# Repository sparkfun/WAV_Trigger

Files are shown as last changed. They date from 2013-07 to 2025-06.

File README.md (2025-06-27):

WAV Trigger
===============

WAV Trigger (https://www.sparkfun.com/products/13660)

[*WAV Trigger (WIG-13660)*](https://www.sparkfun.com/products/13660)

The WAV Trigger is similar to its cousin, the MP3 Trigger, however it plays .WAV files and allows them to be mixed on the fly. 

This board was created in Eagle v6.0.5.

Repository Contents
-------------------

* **/Hardware** - Eagle PCB layout files (.brd, .sch)
* **/Production** - Test bed files and production panel files

Documentation
--------------
* **[Arduino Library](https://github.com/robertsonics/WAV-Trigger-Arduino-Serial-Library)** - Arduino library for the WAV Trigger.
* **[Hookup Guide](https://learn.sparkfun.com/tutorials/wav-trigger-hookup-guide-v11)** - Basic hookup guide for the WAV Trigger.

Product Versions
----------------
* [WIG-13660](https://www.sparkfun.com/products/13660) - vH1.1
* [WIG-12897](https://www.sparkfun.com/products/12897) - vH1.1
* [WIG-13660](https://www.sparkfun.com/products/12000) - vH1.0

Version History
---------------
* vH11
* vH10 - First production run.

License Information
-------------------
All contents of this repository are released under [Creative Commons Share-alike 3.0](http://creativecommons.org/licenses/by-sa/3.0/).

Authors
--------
Jamie Robertson @ robertsonics
Jordan McConnell @ SparkFun Electronics

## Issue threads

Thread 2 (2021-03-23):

WTrigAdvanced won't compile on teensy 3.5

jackjaquejack, 2021-03-23:
Hi there.

Im trying to control the wav trigger via serial communication on the teensy 3.5, but it won't compile. It will compile with the teensy 3.6, and other teensy boards.  does anyone know what I could do to fix this? The project is large and has various pin expansion chips, rgb screens already. The awesome wav trigger is the final piece in the project, so it would be nice to be able to get it to compile. I've checked that I have the correct libs installed, and as I say it compiles on other teensy boards. Any help would be appreciated. error messages to follow, thank you!

/Users/Home/Documents/Arduino/libraries/Metro/Metro.cpp:42:16: warning: extra tokens at end of #ifdef directive
  #ifdef NOCATCH-UP
                ^
In file included from /Users/Home/Documents/Arduino/libraries/AltSoftSerial/AltSoftSerial.cpp:32:0:
/Users/Home/Documents/Arduino/libraries/AltSoftSerial/config/AltSoftSerial_Boards.h:136:2: error: #error "Please define your board timer and pins"
 #error "Please define your board timer and pins"
  ^
/Users/Home/Documents/Arduino/libraries/AltSoftSerial/AltSoftSerial.cpp: In static member function 'static void AltSoftSerial::init(uint32_t)':
/Users/Home/Documents/Arduino/libraries/AltSoftSerial/AltSoftSerial.cpp:68:27: error: 'CONFIG_TIMER_NOPRESCALE' was not declared in this scope
   CONFIG_TIMER_NOPRESCALE();
                           ^
/Users/Home/Documents/Arduino/libraries/AltSoftSerial/AltSoftSerial.cpp:72:28: error: 'CONFIG_TIMER_PRESCALE_8' was not declared in this scope
    CONFIG_TIMER_PRESCALE_8();
                            ^
/Users/Home/Documents/Arduino/libraries/AltSoftSerial/AltSoftSerial.cpp:79:10: error: 'INPUT_CAPTURE_PIN' was not declared in this scope
  pinMode(INPUT_CAPTURE_PIN, INPUT_PULLUP);
          ^
/Users/Home/Documents/Arduino/libraries/AltSoftSerial/AltSoftSerial.cpp:80:15: error: 'OUTPUT_COMPARE_A_PIN' was not declared in this scope
  digitalWrite(OUTPUT_COMPARE_A_PIN, HIGH);
               ^
/Users/Home/Documents/Arduino/libraries/AltSoftSerial/AltSoftSerial.cpp:88:27: error: 'ENABLE_INT_INPUT_CAPTURE' was not declared in this scope
  ENABLE_INT_INPUT_CAPTURE();
                           ^
/Users/Home/Documents/Arduino/libraries/AltSoftSerial/AltSoftSerial.cpp: In static member function 'static void AltSoftSerial::end()':
/Users/Home/Documents/Arduino/libraries/AltSoftSerial/AltSoftSerial.cpp:93:24: error: 'DISABLE_INT_COMPARE_B' was not declared in this scope
  DISABLE_INT_COMPARE_B();
                        ^
/Users/Home/Documents/Arduino/libraries/AltSoftSerial/AltSoftSerial.cpp:94:28: error: 'DISABLE_INT_INPUT_CAPTURE' was not declared in this scope
  DISABLE_INT_INPUT_CAPTURE();
                            ^
/Users/Home/Documents/Arduino/libraries/AltSoftSerial/AltSoftSerial.cpp:97:24: error: 'DISABLE_INT_COMPARE_A' was not declared in this scope
  DISABLE_INT_COMPARE_A();
                        ^
/Users/Home/Documents/Arduino/libraries/AltSoftSerial/AltSoftSerial.cpp: In static member function 'static void AltSoftSerial::writeByte(uint8_t)':
/Users/Home/Documents/Arduino/libraries/AltSoftSerial/AltSoftSerial.cpp:122:24: error: 'ENABLE_INT_COMPARE_A' was not declared in this scope
   ENABLE_INT_COMPARE_A();
                        ^
/Users/Home/Documents/Arduino/libraries/AltSoftSerial/AltSoftSerial.cpp:123:22: error: 'CONFIG_MATCH_CLEAR' was not declared in this scope
   CONFIG_MATCH_CLEAR();
                      ^
/Users/Home/Documents/Arduino/libraries/AltSoftSerial/AltSoftSerial.cpp:124:33: error: 'GET_TIMER_COUNT' was not declared in this scope
   SET_COMPARE_A(GET_TIMER_COUNT() + 16);
                                 ^
/Users/Home/Documents/Arduino/libraries/AltSoftSerial/AltSoftSerial.cpp:124:39: error: 'SET_COMPARE_A' was not declared in this scope
   SET_COMPARE_A(GET_TIMER_COUNT() + 16);
                                       ^
/Users/Home/Documents/Arduino/libraries/AltSoftSerial/AltSoftSerial.cpp: At global scope:
/Users/Home/Documents/Arduino/libraries/AltSoftSerial/AltSoftSerial.cpp:130:4: error: expected constructor, destructor, or type conversion before '(' token
 ISR(COMPARE_A_INTERRUPT)
    ^
/Users/Home/Documents/Arduino/libraries/AltSoftSerial/AltSoftSerial.cpp:43:16: warning: 'rx_byte' defined but not used [-Wunused-variable]
 static uint8_t rx_byte;
                ^
/Users/Home/Documents/Arduino/libraries/AltSoftSerial/AltSoftSerial.cpp:44:16: warning: 'rx_bit' defined but not used [-Wunused-variable]
 static uint8_t rx_bit = 0;
                ^
/Users/Home/Documents/Arduino/libraries/AltSoftSerial/AltSoftSerial.cpp:45:17: warning: 'rx_target' defined but not used [-Wunused-variable]
 static uint16_t rx_target;
                 ^
Multiple libraries were found for "Metro.h"
 Used: /Users/Home/Documents/Arduino/libraries/Metro
 Not used: /private/var/folders/lc/3yqb2gz925d1czhsmn2cnz4r0000gn/T/AppTranslocation/9FE4EA52-FF66-48F3-A1C6-21D8DF2A8493/d/Teensyduino.app/Contents/Java/hardware/teensy/avr/libraries/Metro
Multiple libraries were found for "AltSoftSerial.h"
 Used: /Users/Home/Documents/Arduino/libraries/AltSoftSerial
 Not used: /Users/Home/Documents/Arduino/libraries/AltSoftSerial-master
 Not used: /private/var/folders/lc/3yqb2gz925d1czhsmn2cnz4r0000gn/T/AppTranslocation/9FE4EA52-FF66-48F3-A1C6-21D8DF2A8493/d/Teensyduino.app/Contents/Java/hardware/teensy/avr/libraries/AltSoftSerial
Error compiling for board Teensy 3.5.

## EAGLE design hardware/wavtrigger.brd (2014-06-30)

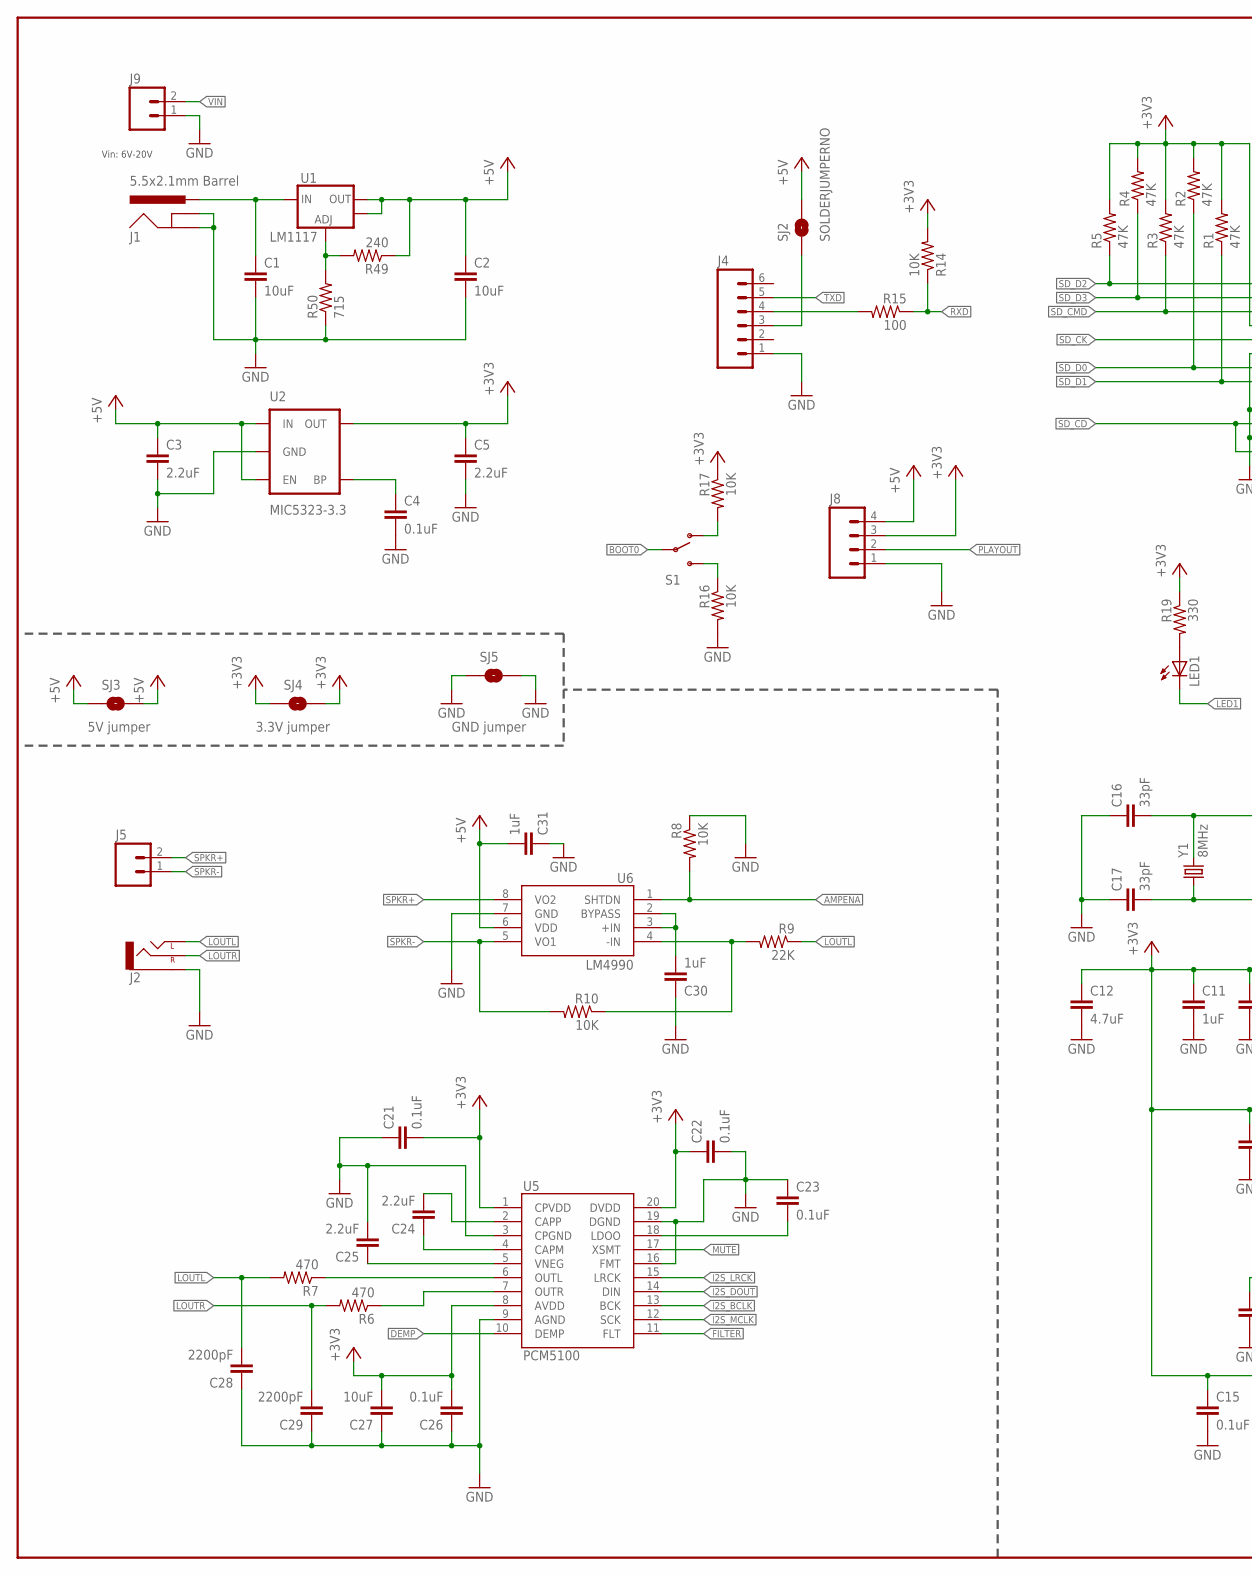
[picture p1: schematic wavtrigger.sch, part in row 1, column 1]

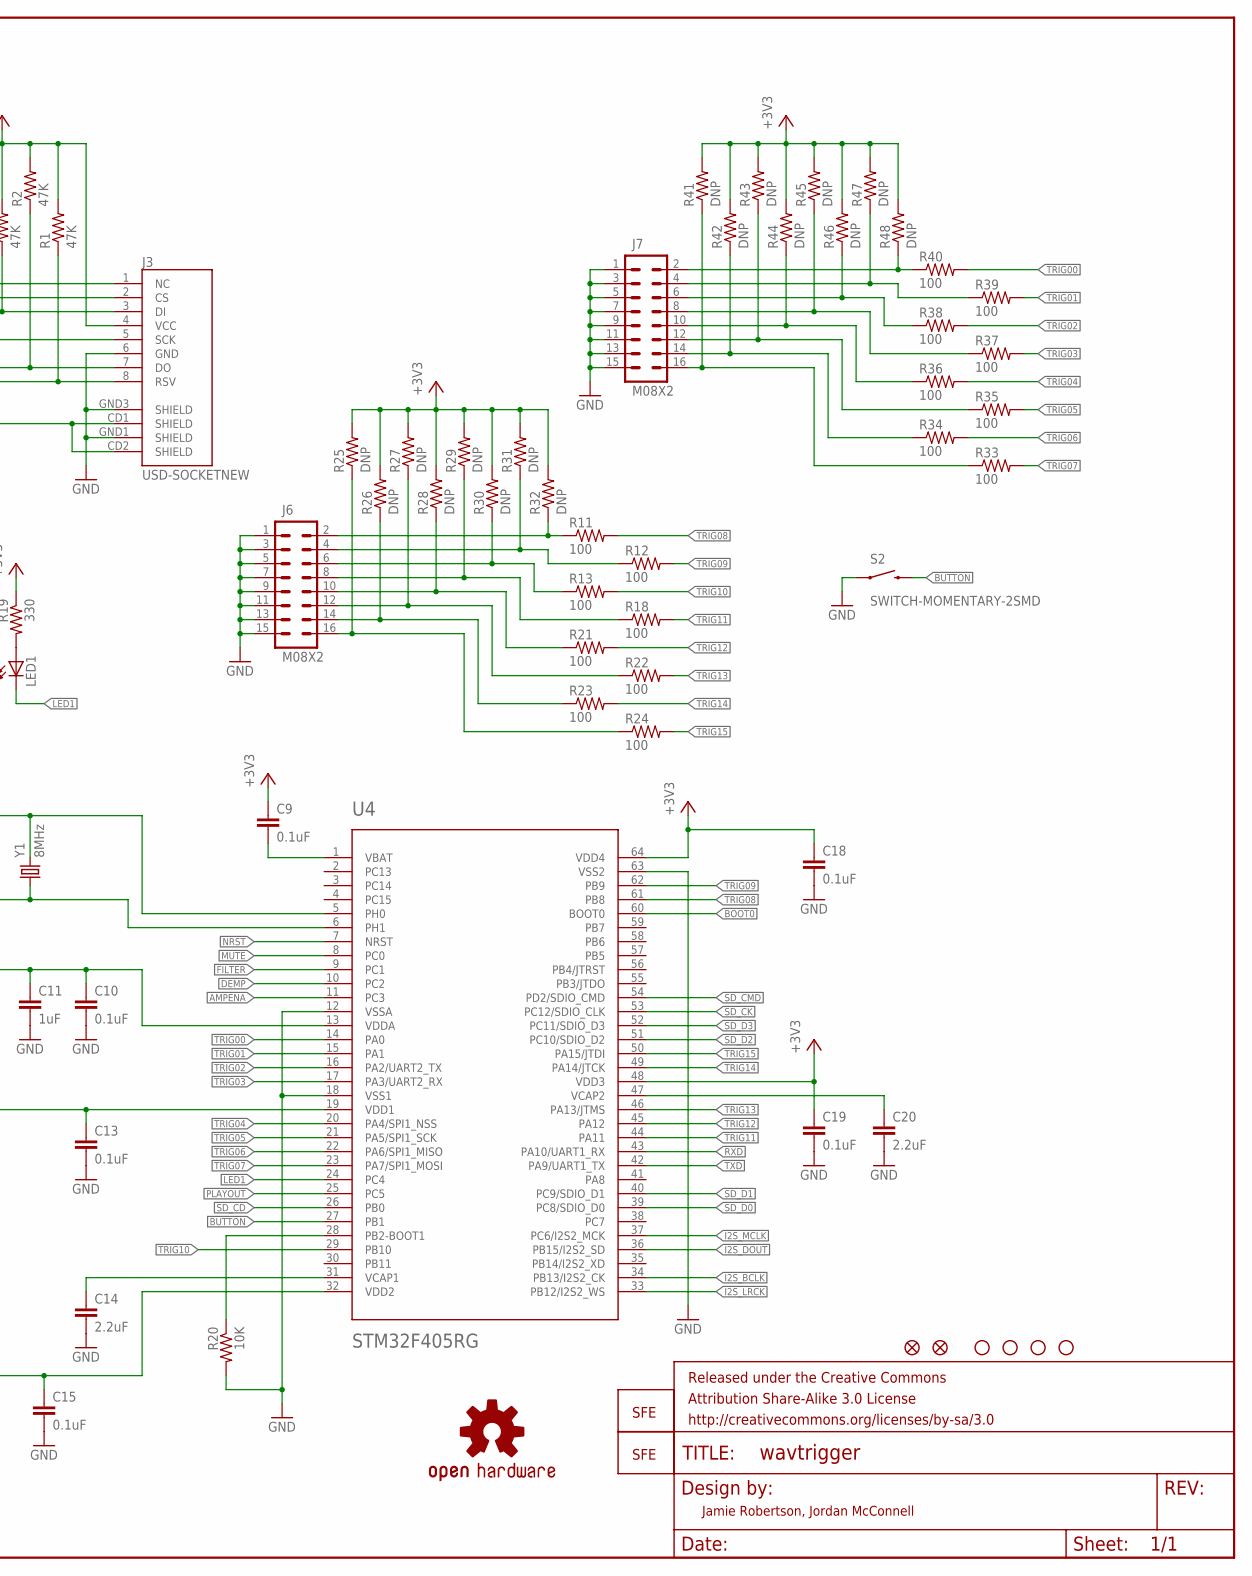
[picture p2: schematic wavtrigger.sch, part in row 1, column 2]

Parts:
C1: 10uF; 1210
C2: 10uF; 0805
C3, C5: 2.2uF; 0805
C4, C9, C10, C13, C15, C18, C19, C21, C22, C23, C26: 0.1uF; 0603-CAP
C11, C30, C31: 1uF; 0603-CAP
C12: 4.7uF; 0603-CAP
C14, C20, C24, C25: 2.2uF; 0603-CAP
C16, C17: 33pF; 0603-CAP
C27: 10uF; 0603-CAP
C28, C29: 2200pF; 0603-CAP
FID1, FID2: FIDUCIAL1X2; FIDUCIAL-1X2
FRAME2: FRAME-LEDGER; CREATIVE_COMMONS
J1: 5.5x2.1mm Barrel; POWER_JACK_SMD
J2: AUDIO-JACKSMD2; AUDIO-JACK-3.5MM-SMD
J3: USD-SOCKETNEW; MICRO-SD-SOCKET-PP
J4: M06SIP; 1X06
J5, J9: M02PTH; 1X02
J6, J7: M08X2; 2X8
J8: M04PTH; 1X04
LED1: LED0603; LED-0603
LOGO1: OSHW-LOGOL; OSHW-LOGO-L
LOGO2: LOGO-SFENEW; SFE-NEW-WEBLOGO
LOGO3: LOGO-SFESK; SFE-LOGO-FLAME
R1, R2, R3, R4, R5: 47K; 0603-RES
R6, R7: 470; 0603-RES
R8, R10, R14, R16, R17, R20: 10K; 0603-RES
R9: 22K; 0603-RES
R11, R12, R13, R15, R18, R21, R22, R23, R24, R33, R34, R35, R36, R37, R38, R39, R40: 100; 0603-RES
R19: 330; 0603-RES
R25, R26, R27, R28, R29, R30, R31, R32, R41, R42, R43, R44, R45, R46, R47, R48: DNP; 0603-RES
R49: 240; 0603-RES
R50: 715; 0603-RES
S1: SWITCH-SPDT-SMD-A; SWITCH-SPST-SMD-A
S2: SWITCH-MOMENTARY-2SMD; TACTILE_SWITCH_SMD
SJ2: SOLDERJUMPERNO; SJ_2S-NO
SJ3, SJ4, SJ5: SOLDERJUMPERTRACE; SJ_2S-TRACE
STANDOFF1, STANDOFF2, STANDOFF3, STANDOFF4: STAND-OFF
U1: V_REG_LM1117SOT223; SOT223
U2: MIC5323-3.3; SOT23-5
U4: STM32F405RG; TQFP64
U5: PCM5100; PW_R-PDSO-G20
U6: LM4990; S-PDSO-G08
Y1: 8MHz; HC49UP

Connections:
+5V: C2.1, C3.1, C31.2, J8.4, R49.1, SJ2.2, SJ3.1, SJ3.2, U1.2 (OUT), U1.4 (OUT), U2.1 (IN), U2.3 (EN), U6.6 (VDD)
AMPENA: R8.2, U4.11 (PC3), U6.1 (SHTDN)
BOOT0: S1.2, U4.60 (BOOT0)
BUTTON: S2.3 (2), U4.27 (PB1)
DEMP: U4.10 (PC2), U5.10 (DEMP)
FILTER: U4.9 (PC1), U5.11 (FLT)
GND: C1.2, C2.2, C3.2, C4.2, C5.2, C10.2, C11.2, C12.2, C13.2, C14.2, C15.2, C16.1, C17.1, C18.2, C19.2, C20.2, C21.1, C22.2, C23.1, C25.2, C26.1, C27.1, C28.1, C29.1, C30.1, C31.1, J1.GND (GNDBREAK), J1.P$4 (GND), J2.SLEEVE, J3.6 (GND), J3.GND1 (SHIELD), J3.GND3 (SHIELD), J4.1, J6.1, J6.3, J6.5, J6.7, J6.9, J6.11, J6.13, J6.15, J7.1, J7.3, J7.5, J7.7, J7.9, J7.11, J7.13, J7.15, J8.1, J9.1, R8.1, R16.2, R20.2, R50.1, S2.1, SJ5.1, SJ5.2, U2.2 (GND), U4.12 (VSSA), U4.18 (VSS1), U4.63 (VSS2), U5.3 (CPGND), U5.9 (AGND), U5.16 (FMT), U5.19 (DGND), U6.7 (GND)
I2S_BCLK: U4.34 (PB13/I2S2_CK), U5.13 (BCK)
I2S_DOUT: U4.36 (PB15/I2S2_SD), U5.14 (DIN)
I2S_LRCK: U4.33 (PB12/I2S2_WS), U5.15 (LRCK)
I2S_MCLK: U4.37 (PC6/I2S2_MCK), U5.12 (SCK)
LED1: LED1.C, U4.24 (PC4)
LOUTL: C28.2, J2.TIP (LEFT), R7.2, R9.1
LOUTR: C29.2, J2.RING (RIGHT), R6.2
MUTE: U4.8 (PC0), U5.17 (XSMT)
unnamed: J6.2, R11.1, R32.1
unnamed: C4.1, U2.4 (BP)
unnamed: C9.2, U4.1 (VBAT)
unnamed: C14.1, U4.31 (VCAP1)
unnamed: C16.2, U4.5 (PH0), Y1.2
unnamed: C17.2, U4.6 (PH1), Y1.1
unnamed: R16.1, S1.3 (S)
unnamed: C20.1, U4.47 (VCAP2)
unnamed: J4.4, R15.2
unnamed: R17.2, S1.1 (O)
unnamed: LED1.A, R19.2
unnamed: R20.1, U4.28 (PB2-BOOT1)
unnamed: R49.2, R50.2, U1.1 (ADJ)
unnamed: C23.2, U5.18 (LDOO)
unnamed: R6.1, U5.7 (OUTR)
unnamed: C24.2, U5.2 (CAPP)
unnamed: C24.1, U5.4 (CAPM)
unnamed: C25.1, U5.5 (VNEG)
unnamed: R7.1, U5.6 (OUTL)
unnamed: C30.2, U6.2 (BYPASS), U6.3 (+IN)
unnamed: J6.4, R12.1, R31.1
unnamed: J6.6, R13.1, R30.1
unnamed: J6.8, R18.1, R29.1
unnamed: J6.10, R21.1, R28.1
unnamed: J6.12, R22.1, R27.1
unnamed: J6.14, R23.1, R26.1
unnamed: R9.2, R10.1, U6.4 (-IN)
unnamed: J6.16, R24.1, R25.1
unnamed: J4.3, SJ2.1
unnamed: J7.2, R40.1, R48.1
unnamed: J7.4, R39.1, R47.1
unnamed: J7.6, R38.1, R46.1
unnamed: J7.8, R37.1, R45.1
unnamed: J7.10, R36.1, R44.1
unnamed: J7.12, R35.1, R43.1
unnamed: J7.14, R34.1, R42.1
unnamed: J7.16, R33.1, R41.1
NRST: U4.7 (NRST)
PLAYOUT: J8.2, U4.25 (PC5)
RXD: R14.1, R15.1, U4.43 (PA10/UART1_RX)
SD_CD: J3.CD1 (SHIELD), J3.CD2 (SHIELD), U4.26 (PB0)
SD_CK: J3.5 (SCK), U4.53 (PC12/SDIO_CLK)
SD_CMD: J3.3 (DI), R3.1, U4.54 (PD2/SDIO_CMD)
SD_D0: J3.7 (DO), R2.1, U4.39 (PC8/SDIO_D0)
SD_D1: J3.8 (RSV), R1.1, U4.40 (PC9/SDIO_D1)
SD_D2: J3.1 (NC), R5.1, U4.51 (PC10/SDIO_D2)
SD_D3: J3.2 (CS), R4.1, U4.52 (PC11/SDIO_D3)
SPKR+: J5.2, U6.8 (VO2)
SPKR-: J5.1, R10.2, U6.5 (VO1)
TRIG00: R40.2, U4.14 (PA0)
TRIG01: R39.2, U4.15 (PA1)
TRIG02: R38.2, U4.16 (PA2/UART2_TX)
TRIG03: R37.2, U4.17 (PA3/UART2_RX)
TRIG04: R36.2, U4.20 (PA4/SPI1_NSS)
TRIG05: R35.2, U4.21 (PA5/SPI1_SCK)
TRIG06: R34.2, U4.22 (PA6/SPI1_MISO)
TRIG07: R33.2, U4.23 (PA7/SPI1_MOSI)
TRIG08: R11.2, U4.61 (PB8)
TRIG09: R12.2, U4.62 (PB9)
TRIG10: R13.2, U4.29 (PB10)
TRIG11: R18.2, U4.44 (PA11)
TRIG12: R21.2, U4.45 (PA12)
TRIG13: R22.2, U4.46 (PA13/JTMS)
TRIG14: R23.2, U4.49 (PA14/JTCK)
TRIG15: R24.2, U4.50 (PA15/JTDI)
TXD: J4.5, U4.42 (PA9/UART1_TX)
VCC: C5.1, C9.1, C10.1, C11.1, C12.1, C13.1, C15.1, C18.1, C19.1, C21.2, C22.1, C26.2, C27.2, J3.4 (VCC), J8.3, R1.2, R2.2, R3.2, R4.2, R5.2, R14.2, R17.1, R19.1, R25.2, R26.2, R27.2, R28.2, R29.2, R30.2, R31.2, R32.2, R41.2, R42.2, R43.2, R44.2, R45.2, R46.2, R47.2, R48.2, SJ4.1, SJ4.2, U2.5 (OUT), U4.13 (VDDA), U4.19 (VDD1), U4.32 (VDD2), U4.48 (VDD3), U4.64 (VDD4), U5.1 (CPVDD), U5.8 (AVDD), U5.20 (DVDD)
VIN: C1.1, J1.VIN0 (PWR), J9.2, U1.3 (IN)

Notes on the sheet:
Jamie Robertson, Jordan McConnell
5V jumper
3.3V jumper
GND jumper
LM1117
Vin: 6V-20V

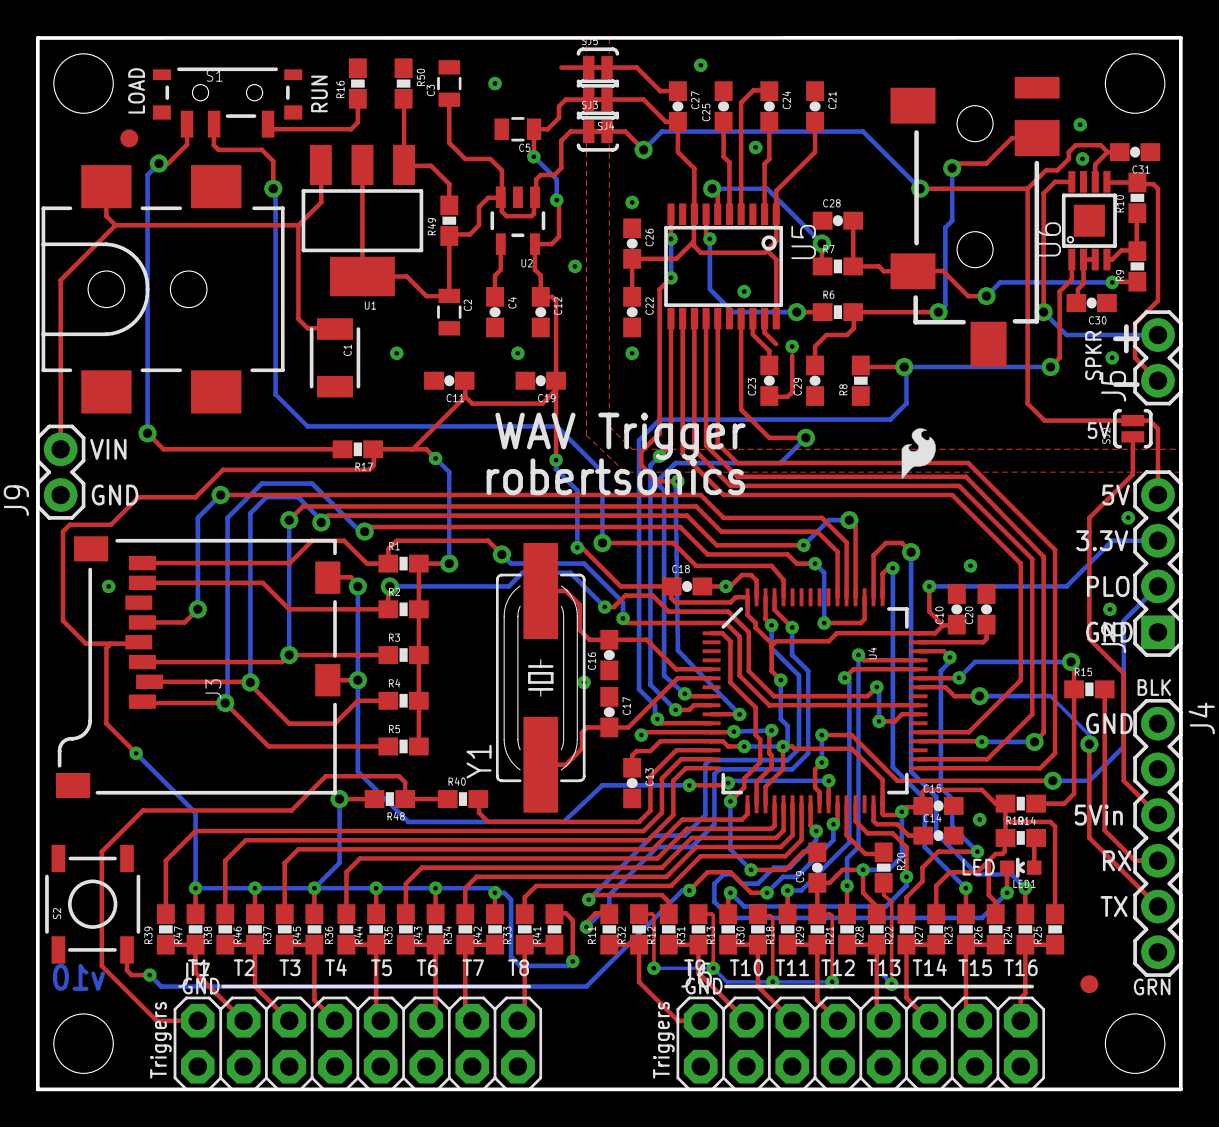
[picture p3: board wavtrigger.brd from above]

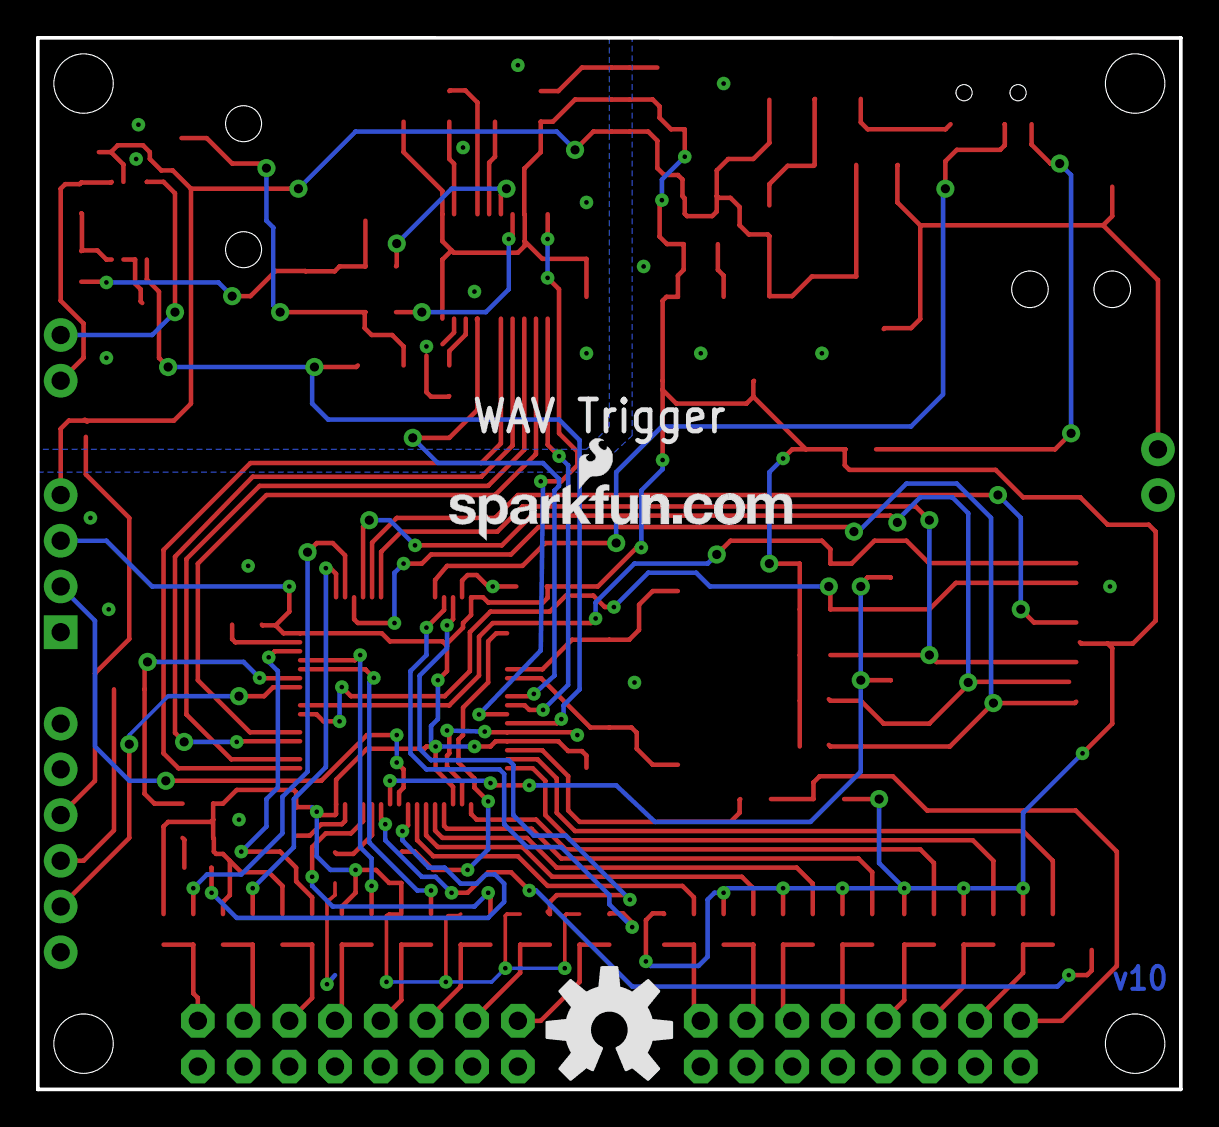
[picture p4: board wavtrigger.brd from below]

Board: 2 copper layers, 63.5 x 58.4 mm, 110 parts (2 on the bottom side), 82 nets.

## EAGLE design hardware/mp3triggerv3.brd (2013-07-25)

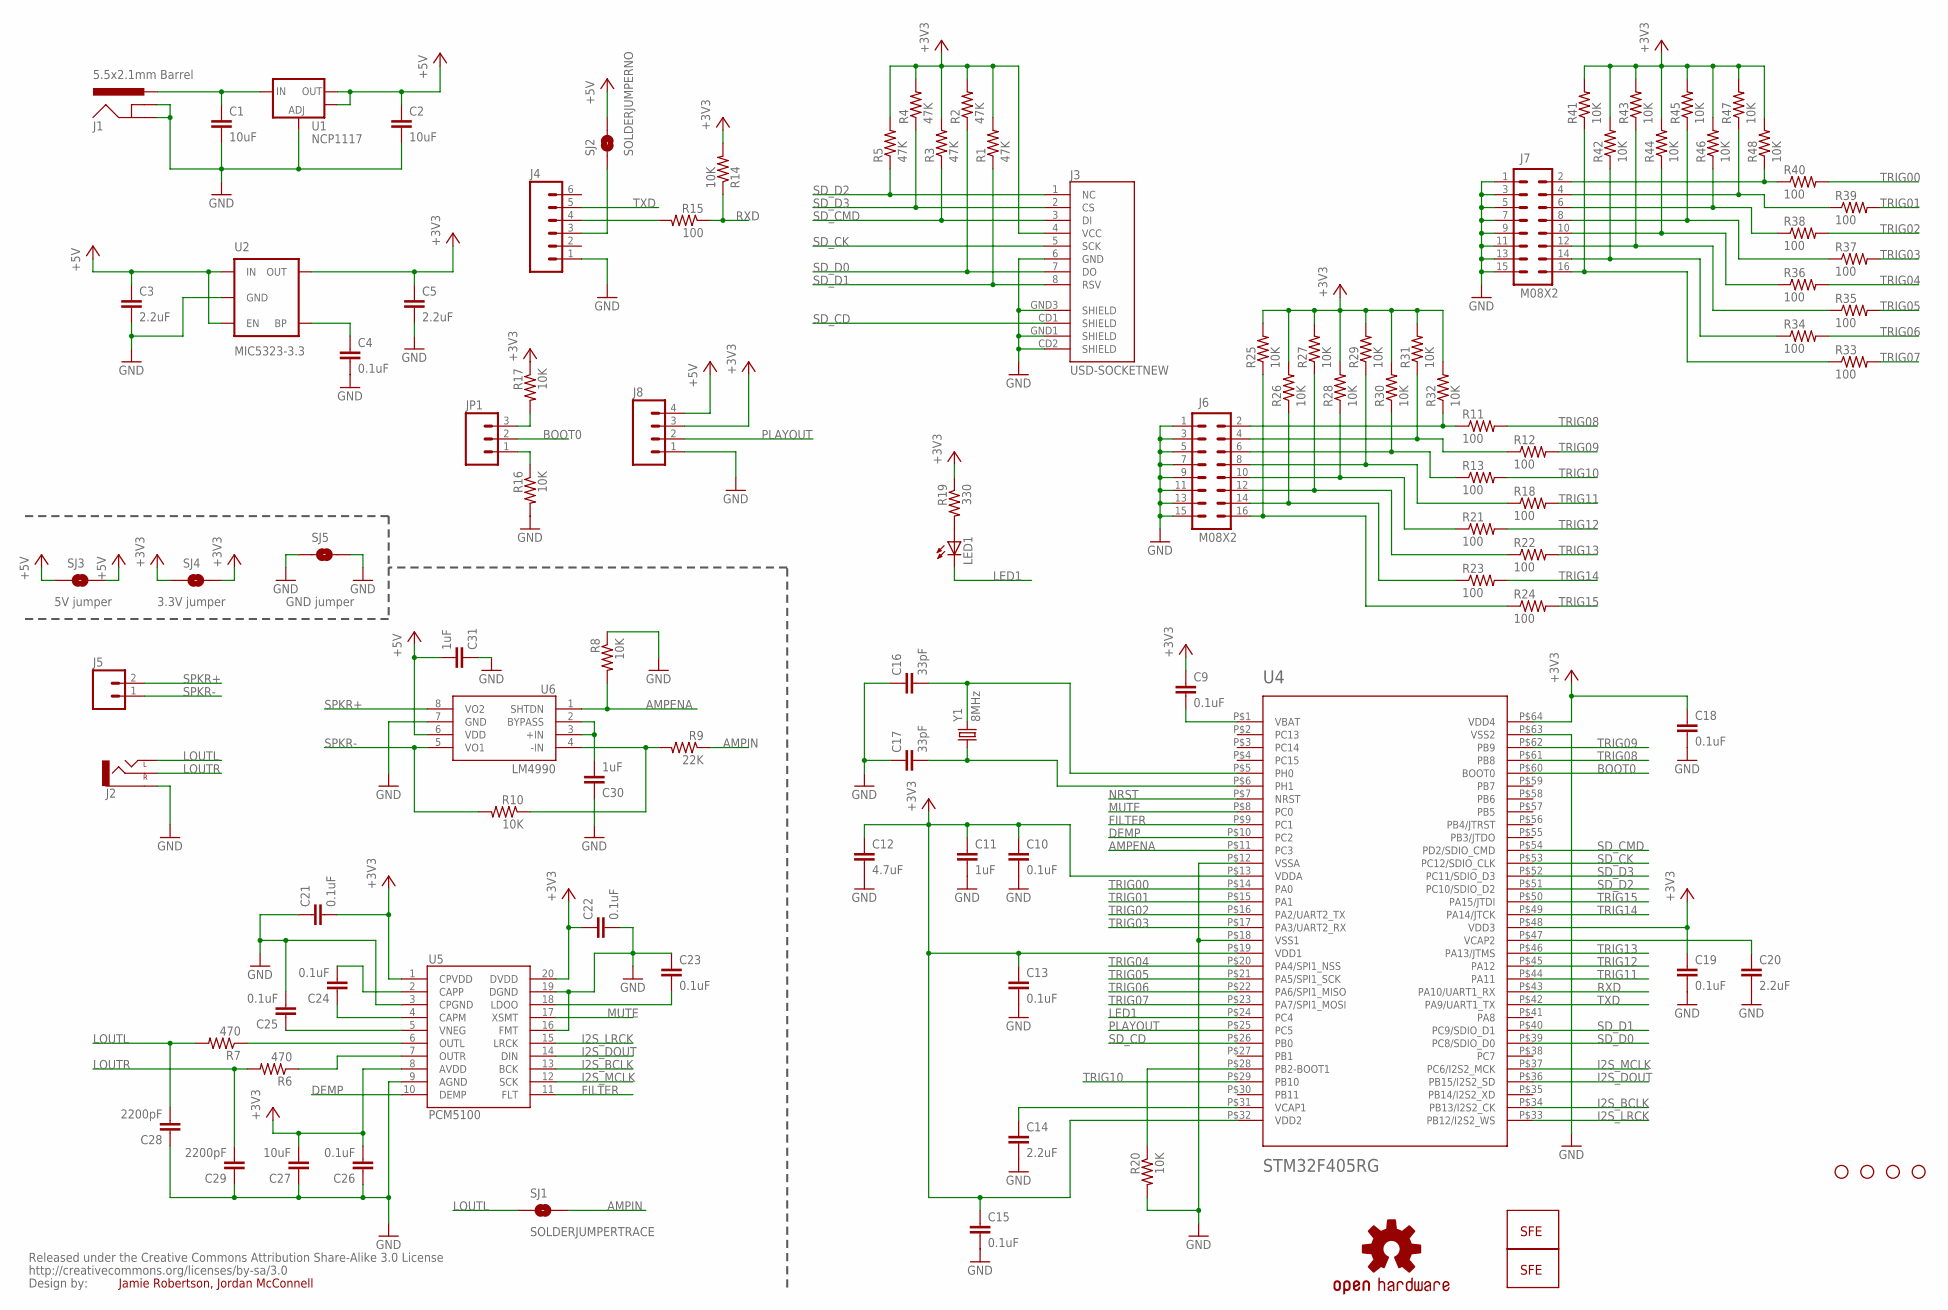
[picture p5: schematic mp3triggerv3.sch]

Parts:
C1: 10uF; 1210
C2: 10uF; 0805
C3, C5: 2.2uF; 0805
C4, C9, C10, C13, C15, C18, C19, C21, C22, C23, C24, C25, C26: 0.1uF; 0603-CAP
C11, C30, C31: 1uF; 0603-CAP
C12: 4.7uF; 0603-CAP
C14, C20: 2.2uF; 0603-CAP
C16, C17: 33pF; 0603-CAP
C27: 10uF; 0603-CAP
C28, C29: 2200pF; 0603-CAP
CC_TEXT1: CREATIVE_COMMONS
J1: 5.5x2.1mm Barrel; POWER_JACK_SMD
J2: AUDIO-JACKSMD2; AUDIO-JACK-3.5MM-SMD
J3: USD-SOCKETNEW; MICRO-SD-SOCKET-PP
J4: M06SIP; 1X06
J5: M02PTH; 1X02
J6, J7: M08X2; 2X8
J8: M04PTH; 1X04
JP1: M03PTH; 1X03
LED1: LED0603; LED-0603
LOGO1: OSHW-LOGOL; OSHW-LOGO-L
LOGO2: LOGO-SFENEW; SFE-NEW-WEBLOGO
LOGO3: LOGO-SFESK; SFE-LOGO-FLAME
R1, R2, R3, R4, R5: 47K; 0603-RES
R6, R7: 470; 0603-RES
R8, R10, R14, R16, R17, R20, R25, R26, R27, R28, R29, R30, R31, R32, R41, R42, R43, R44, R45, R46, R47, R48: 10K; 0603-RES
R9: 22K; 0603-RES
R11, R12, R13, R15, R18, R21, R22, R23, R24, R33, R34, R35, R36, R37, R38, R39, R40: 100; 0603-RES
R19: 330; 0603-RES
SJ1, SJ3, SJ4, SJ5: SOLDERJUMPERTRACE; SJ_2S-TRACE
SJ2: SOLDERJUMPERNO; SJ_2S-NO
STANDOFF1, STANDOFF2, STANDOFF3, STANDOFF4: STAND-OFF
U1: NCP1117; SOT223
U2: MIC5323-3.3; SOT23-5
U4: STM32F405RG; TQFP-10X10-64
U5: PCM5100; PW_R-PDSO-G20
U6: LM4990; S-PDSO-G08
Y1: 8MHz; HC49UP

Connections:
+5V: C2.1, C3.1, C31.2, J8.4, SJ2.2, SJ3.1, SJ3.2, U1.2 (OUT), U1.4 (OUT), U2.1 (IN), U2.3 (EN), U6.6 (VDD)
AMPENA: R8.2, U4.P$11 (PC3), U6.1 (SHTDN)
AMPIN: R9.1, SJ1.2
BOOT0: JP1.2, U4.P$60 (BOOT0)
DEMP: U4.P$10 (PC2), U5.10 (DEMP)
FILTER: U4.P$9 (PC1), U5.11 (FLT)
GND: C1.2, C2.2, C3.2, C4.2, C5.2, C10.2, C11.2, C12.2, C13.2, C14.2, C15.2, C16.1, C17.1, C18.2, C19.2, C20.2, C21.1, C22.2, C23.1, C25.2, C26.1, C27.1, C28.1, C29.1, C30.1, C31.1, J1.GND (GNDBREAK), J1.P$4 (GND), J2.SLEEVE, J3.6 (GND), J3.CD2 (SHIELD), J3.GND1 (SHIELD), J3.GND3 (SHIELD), J4.1, J6.1, J6.3, J6.5, J6.7, J6.9, J6.11, J6.13, J6.15, J7.1, J7.3, J7.5, J7.7, J7.9, J7.11, J7.13, J7.15, J8.1, R8.1, R16.2, R20.2, SJ5.1, SJ5.2, U1.1 (ADJ), U2.2 (GND), U4.P$12 (VSSA), U4.P$18 (VSS1), U4.P$63 (VSS2), U5.3 (CPGND), U5.9 (AGND), U5.16 (FMT), U5.19 (DGND), U6.7 (GND)
I2S_BCLK: U4.P$34 (PB13/I2S2_CK), U5.13 (BCK)
I2S_DOUT: U4.P$36 (PB15/I2S2_SD), U5.14 (DIN)
I2S_LRCK: U4.P$33 (PB12/I2S2_WS), U5.15 (LRCK)
I2S_MCLK: U4.P$37 (PC6/I2S2_MCK), U5.12 (SCK)
LED1: LED1.C, U4.P$24 (PC4)
LOUTL: C28.2, J2.TIP (LEFT), R7.2, SJ1.1
LOUTR: C29.2, J2.RING (RIGHT), R6.2
MUTE: U4.P$8 (PC0), U5.17 (XSMT)
unnamed: J6.2, R11.1, R32.1
unnamed: C4.1, U2.4 (BP)
unnamed: C9.2, U4.P$1 (VBAT)
unnamed: C14.1, U4.P$31 (VCAP1)
unnamed: C16.2, U4.P$5 (PH0), Y1.2
unnamed: C17.2, U4.P$6 (PH1), Y1.1
unnamed: JP1.1, R16.1
unnamed: C20.1, U4.P$47 (VCAP2)
unnamed: J4.4, R15.2
unnamed: JP1.3, R17.2
unnamed: LED1.A, R19.2
unnamed: R20.1, U4.P$28 (PB2-BOOT1)
unnamed: C23.2, U5.18 (LDOO)
unnamed: R6.1, U5.7 (OUTR)
unnamed: C24.2, U5.2 (CAPP)
unnamed: C24.1, U5.4 (CAPM)
unnamed: C25.1, U5.5 (VNEG)
unnamed: R7.1, U5.6 (OUTL)
unnamed: C30.2, U6.2 (BYPASS), U6.3 (+IN)
unnamed: J6.4, R12.1, R31.1
unnamed: J6.6, R13.1, R30.1
unnamed: J6.8, R18.1, R29.1
unnamed: J6.10, R21.1, R28.1
unnamed: J6.12, R22.1, R27.1
unnamed: J6.14, R23.1, R26.1
unnamed: R9.2, R10.1, U6.4 (-IN)
unnamed: J6.16, R24.1, R25.1
unnamed: J4.3, SJ2.1
unnamed: J7.2, R40.1, R48.1
unnamed: J7.4, R39.1, R47.1
unnamed: J7.6, R38.1, R46.1
unnamed: J7.8, R37.1, R45.1
unnamed: J7.10, R36.1, R44.1
unnamed: J7.12, R35.1, R43.1
unnamed: J7.14, R34.1, R42.1
unnamed: J7.16, R33.1, R41.1
NRST: U4.P$7 (NRST)
PLAYOUT: J8.2, U4.P$25 (PC5)
RXD: R14.1, R15.1, U4.P$43 (PA10/UART1_RX)
SD_CD: J3.CD1 (SHIELD), U4.P$26 (PB0)
SD_CK: J3.5 (SCK), U4.P$53 (PC12/SDIO_CLK)
SD_CMD: J3.3 (DI), R3.1, U4.P$54 (PD2/SDIO_CMD)
SD_D0: J3.7 (DO), R2.1, U4.P$39 (PC8/SDIO_D0)
SD_D1: J3.8 (RSV), R1.1, U4.P$40 (PC9/SDIO_D1)
SD_D2: J3.1 (NC), R5.1, U4.P$51 (PC10/SDIO_D2)
SD_D3: J3.2 (CS), R4.1, U4.P$52 (PC11/SDIO_D3)
SPKR+: J5.2, U6.8 (VO2)
SPKR-: J5.1, R10.2, U6.5 (VO1)
TRIG00: R40.2, U4.P$14 (PA0)
TRIG01: R39.2, U4.P$15 (PA1)
TRIG02: R38.2, U4.P$16 (PA2/UART2_TX)
TRIG03: R37.2, U4.P$17 (PA3/UART2_RX)
TRIG04: R36.2, U4.P$20 (PA4/SPI1_NSS)
TRIG05: R35.2, U4.P$21 (PA5/SPI1_SCK)
TRIG06: R34.2, U4.P$22 (PA6/SPI1_MISO)
TRIG07: R33.2, U4.P$23 (PA7/SPI1_MOSI)
TRIG08: R11.2, U4.P$61 (PB8)
TRIG09: R12.2, U4.P$62 (PB9)
TRIG10: R13.2, U4.P$29 (PB10)
TRIG11: R18.2, U4.P$44 (PA11)
TRIG12: R21.2, U4.P$45 (PA12)
TRIG13: R22.2, U4.P$46 (PA13/JTMS)
TRIG14: R23.2, U4.P$49 (PA14/JTCK)
TRIG15: R24.2, U4.P$50 (PA15/JTDI)
TXD: J4.5, U4.P$42 (PA9/UART1_TX)
VCC: C5.1, C9.1, C10.1, C11.1, C12.1, C13.1, C15.1, C18.1, C19.1, C21.2, C22.1, C26.2, C27.2, J3.4 (VCC), J8.3, R1.2, R2.2, R3.2, R4.2, R5.2, R14.2, R17.1, R19.1, R25.2, R26.2, R27.2, R28.2, R29.2, R30.2, R31.2, R32.2, R41.2, R42.2, R43.2, R44.2, R45.2, R46.2, R47.2, R48.2, SJ4.1, SJ4.2, U2.5 (OUT), U4.P$13 (VDDA), U4.P$19 (VDD1), U4.P$32 (VDD2), U4.P$48 (VDD3), U4.P$64 (VDD4), U5.1 (CPVDD), U5.8 (AVDD), U5.20 (DVDD)
VIN_9V: C1.1, J1.VIN0 (PWR), U1.3 (IN)

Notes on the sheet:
Jamie Robertson, Jordan McConnell
5V jumper
3.3V jumper
GND jumper

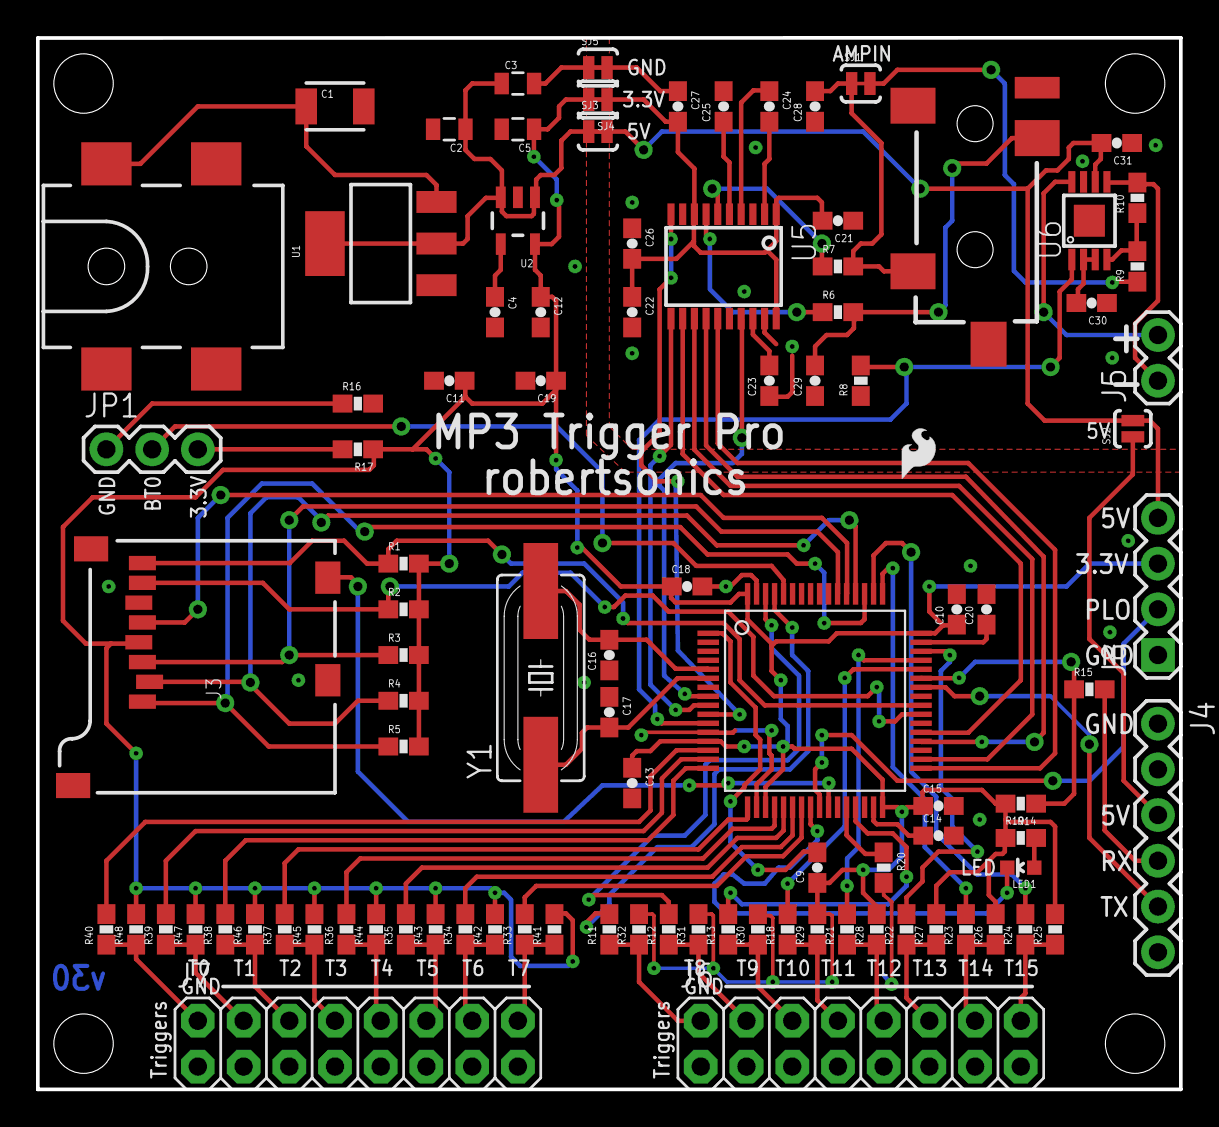
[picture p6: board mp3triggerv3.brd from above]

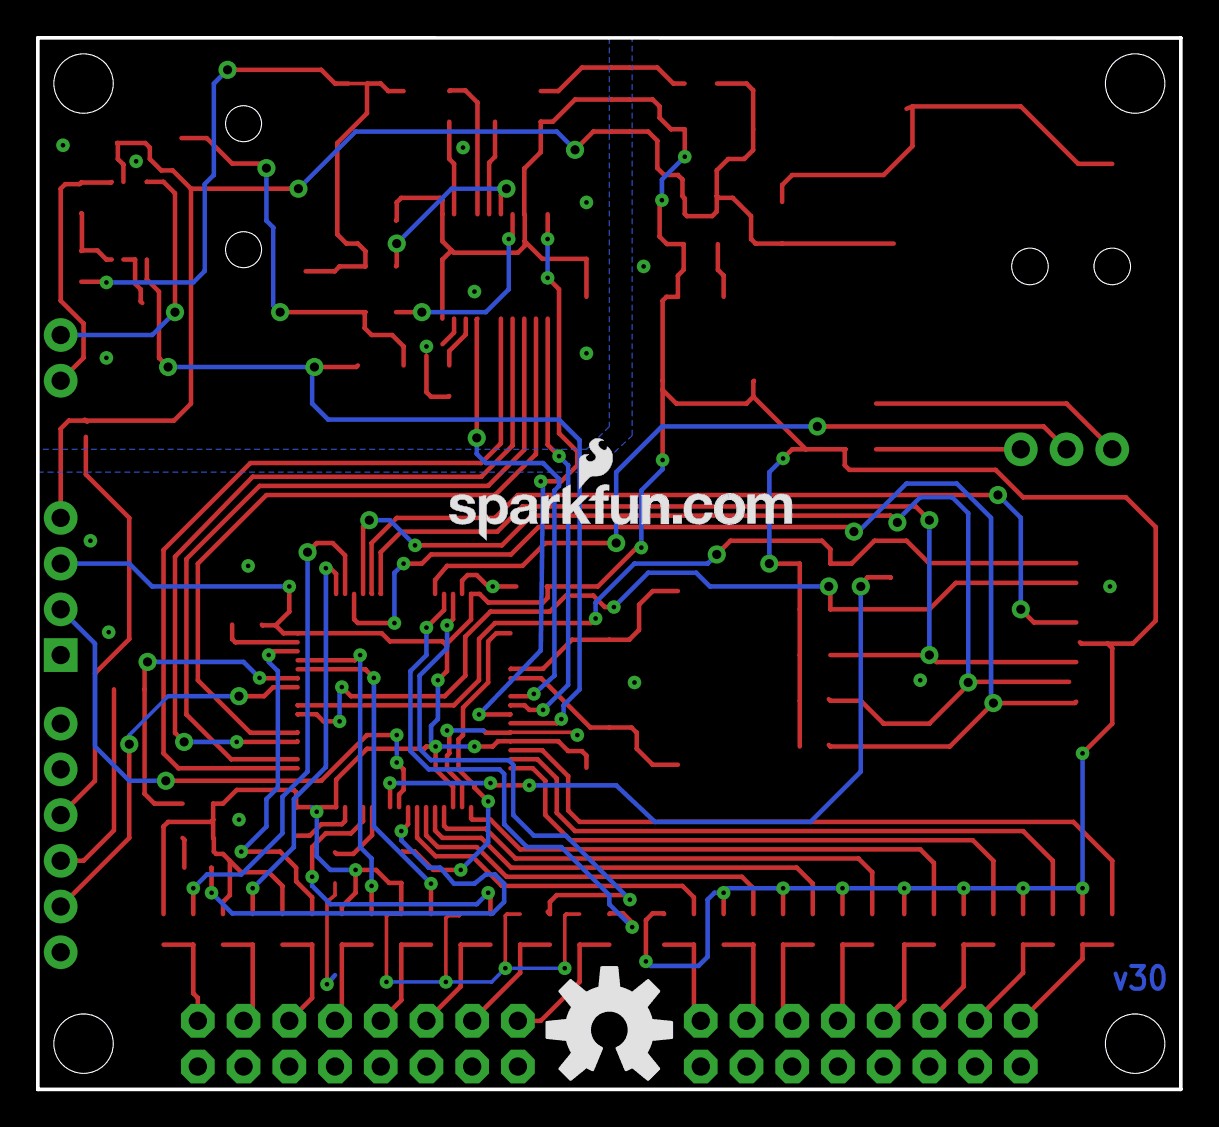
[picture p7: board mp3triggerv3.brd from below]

Board: 2 copper layers, 63.5 x 58.4 mm, 105 parts (2 on the bottom side), 81 nets.

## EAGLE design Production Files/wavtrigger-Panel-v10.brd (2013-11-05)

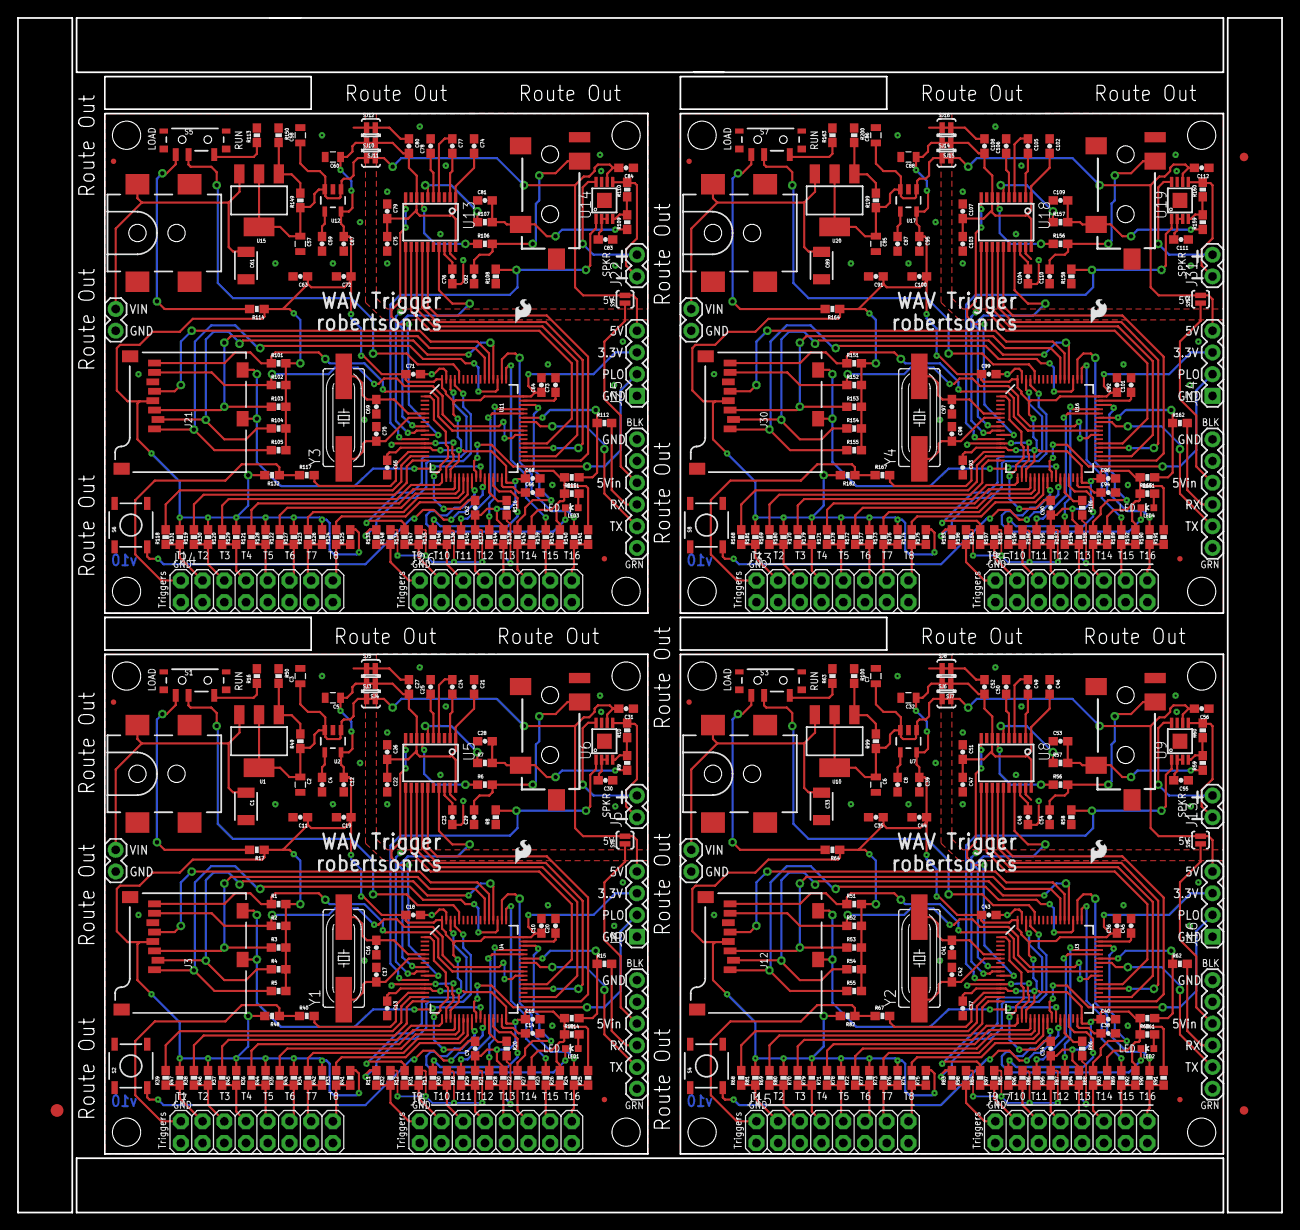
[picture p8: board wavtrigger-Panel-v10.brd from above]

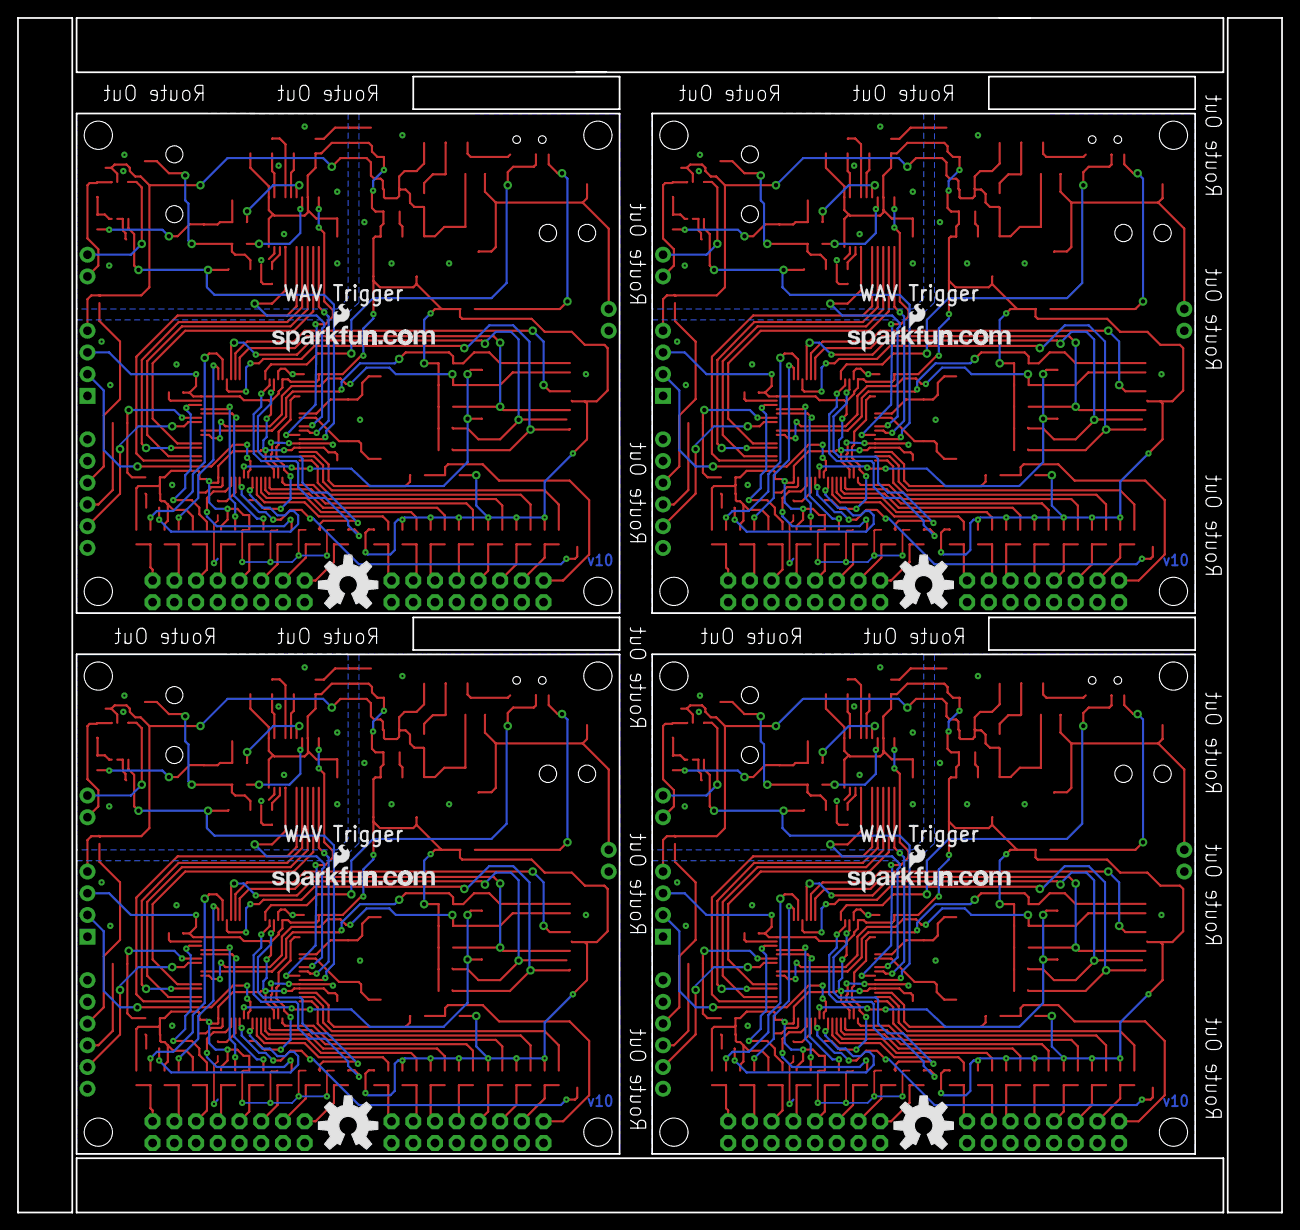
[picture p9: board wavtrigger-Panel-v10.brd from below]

Board: 2 copper layers, 147.8 x 139.7 mm, 439 parts (8 on the bottom side), 328 nets.

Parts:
C1, C33, C61, C89: 10uF; 1210
C2, C6, C57, C85: 10uF; 0805
C3, C5, C7, C32, C58, C60, C86, C88: 2.2uF; 0805
C4, C8, C9, C10, C13, C15, C18, C19, C21, C22, C23, C24, C25, C26, C34, C36, C37, C40, C43, C44, C46, C47, C48, C49, C50, C51, C59, C62, C64, C65, C68, C71, C72, C74, C75, C76, C77, C78, C79, C87, C90, C92, C93, C96, C99, C100, C102, C103, C104, C105, C106, C107: 0.1uF; 0603-CAP
C11, C30, C31, C35, C55, C56, C63, C83, C84, C91, C111, C112: 1uF; 0603-CAP
C12, C39, C67, C95: 4.7uF; 0603-CAP
C14, C20, C38, C45, C66, C73, C94, C101: 2.2uF; 0603-CAP
C16, C17, C41, C42, C69, C70, C97, C98: 33pF; 0603-CAP
C27, C52, C80, C108: 10uF; 0603-CAP
C28, C29, C53, C54, C81, C82, C109, C110: 2200pF; 0603-CAP
E$1: FIDUCIAL-1.5X3
E$4, E$5: FIDUCIAL-1X2
FID1, FID2, FID3, FID4, FID5, FID6, FID7, FID8: FIDUCIALUFIDUCIAL; MICRO-FIDUCIAL
J1, J10, J19, J28: 5.5x2.1mm Barrel; POWER_JACK_SMD
J2, J11, J20, J29: AUDIO-JACK-3.5MM-SMD
J3, J12, J21, J30: USD-SOCKETNEW; MICRO-SD-SOCKET-PP
J4, J14, J23, J32: 1X06
J5, J9, J13, J18, J22, J27, J31, J36: 1X02
J6, J7, J15, J17, J24, J26, J33, J35: M08X2; 2X8
J8, J16, J25, J34: 1X04
LED1, LED2, LED3, LED4: LED-0603
LOGO1, LOGO4, LOGO7, LOGO10: OSHW-LOGOL; OSHW-LOGO-L
LOGO2, LOGO5, LOGO8, LOGO11: LOGO-SFENEW; SFE-NEW-WEBLOGO
LOGO3, LOGO6, LOGO9, LOGO12: LOGO-SFESK; SFE-LOGO-FLAME
R1, R2, R3, R4, R5, R51, R52, R53, R54, R55, R101, R102, R103, R104, R105, R151, R152, R153, R154, R155: 47K; 0603-RES
R6, R7, R56, R57, R106, R107, R156, R157: 470; 0603-RES
R8, R10, R14, R16, R17, R20, R58, R60, R61, R63, R64, R66, R108, R110, R111, R113, R114, R116, R158, R160, R161, R163, R164, R166: 10K; 0603-RES
R9, R59, R109, R159: 22K; 0603-RES
R11, R12, R13, R15, R18, R21, R22, R23, R24, R33, R34, R35, R36, R37, R38, R39, R40, R62, R67, R68, R69, R70, R71, R72, R73, R74, R83, R84, R85, R86, R87, R88, R89, R90, R112, R117, R118, R119, R120, R121, R122, R123, R124, R133, R134, R135, R136, R137, R138, R139, R140, R162, R167, R168, R169, R170, R171, R172, R173, R174, R183, R184, R185, R186, R187, R188, R189, R190: 100; 0603-RES
R19, R65, R115, R165: 330; 0603-RES
R25, R26, R27, R28, R29, R30, R31, R32, R41, R42, R43, R44, R45, R46, R47, R48, R75, R76, R77, R78, R79, R80, R81, R82, R91, R92, R93, R94, R95, R96, R97, R98, R125, R126, R127, R128, R129, R130, R131, R132, R141, R142, R143, R144, R145, R146, R147, R148, R175, R176, R177, R178, R179, R180, R181, R182, R191, R192, R193, R194, R195, R196, R197, R198: DNP; 0603-RES
R49, R99, R149, R199: 240; 0603-RES
R50, R100, R150, R200: 715; 0603-RES
S1, S3, S5, S7: SWITCH-SPST-SMD-A
S2, S4, S6, S8: SWITCH-MOMENTARY-2SMD; TACTILE_SWITCH_SMD
SJ1, SJ2, SJ9, SJ13: SOLDERJUMPERNO; SJ_2S-NO
SJ3, SJ4, SJ5, SJ6, SJ7, SJ8, SJ10, SJ11, SJ12, SJ14, SJ15, SJ16: SOLDERJUMPERTRACE; SJ_2S-TRACE
STANDOFF1, STANDOFF2, STANDOFF3, STANDOFF4, STANDOFF5, STANDOFF6, STANDOFF7, STANDOFF8, STANDOFF9, STANDOFF10, STANDOFF11, STANDOFF12, STANDOFF13, STANDOFF14, STANDOFF15, STANDOFF16: STAND-OFF
U1, U10, U15, U20: SOT223
U2, U7, U12, U17: MIC5323-3.3; SOT23-5
U3, U4, U11, U16: STM32F405RG; TQFP64
U5, U8, U13, U18: PCM5100; PW_R-PDSO-G20
U6, U9, U14, U19: LM4990; S-PDSO-G08
Y1, Y2, Y3, Y4: 8MHz; HC49UP

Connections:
+5V: C2.1, C3.1, C31.2, J8.4, R49.1, SJ2.2, SJ3.1, SJ3.2, U1.2, U1.4, U2.1, U2.3, U6.6
+5V1: C6.1, C7.1, C56.2, J16.4, R99.1, SJ1.2, SJ6.1, SJ6.2, U7.1, U7.3, U9.6, U10.2, U10.4
+5V2: C57.1, C58.1, C84.2, J25.4, R149.1, SJ9.2, SJ10.1, SJ10.2, U12.1, U12.3, U14.6, U15.2, U15.4
+5V3: C85.1, C86.1, C112.2, J34.4, R199.1, SJ13.2, SJ14.1, SJ14.2, U17.1, U17.3, U19.6, U20.2, U20.4
AMPENA: R8.2, U4.11, U6.1
AMPENA1: R58.2, U3.11, U9.1
AMPENA2: R108.2, U11.11, U14.1
AMPENA3: R158.2, U16.11, U19.1
BOOT0: S1.2, U4.60
BOOT1: S3.2, U3.60
BOOT2: S5.2, U11.60
BOOT3: S7.2, U16.60
BUTTON: S2.3, U4.27
BUTTON1: S4.3, U3.27
BUTTON2: S6.3, U11.27
BUTTON3: S8.3, U16.27
DEMP: U4.10, U5.10
DEMP1: U3.10, U8.10
DEMP2: U11.10, U13.10
DEMP3: U16.10, U18.10
FILTER: U4.9, U5.11
FILTER1: U3.9, U8.11
FILTER2: U11.9, U13.11
FILTER3: U16.9, U18.11
GND: C1.2, C2.2, C3.2, C4.2, C5.2, C10.2, C11.2, C12.2, C13.2, C14.2, C15.2, C16.1, C17.1, C18.2, C19.2, C20.2, C21.1, C22.2, C23.1, C25.2, C26.1, C27.1, C28.1, C29.1, C30.1, C31.1, J1.GND, J1.P$4, J2.SLEEVE, J3.6, J3.GND1, J3.GND3, J4.1, J6.1, J6.3, J6.5, J6.7, J6.9, J6.11, J6.13, J6.15, J7.1, J7.3, J7.5, J7.7, J7.9, J7.11, J7.13, J7.15, J8.1, J9.1, R8.1, R16.2, R20.2, R50.1, S2.1, SJ5.1, SJ5.2, U2.2, U4.12, U4.18, U4.63, U5.3, U5.9, U5.16, U5.19, U6.7
GND1: C6.2, C7.2, C8.2, C32.2, C33.2, C35.2, C36.2, C37.2, C38.2, C39.2, C40.2, C41.1, C42.1, C43.2, C44.2, C45.2, C46.1, C47.2, C48.1, C50.2, C51.1, C52.1, C53.1, C54.1, C55.1, C56.1, J10.GND, J10.P$4, J11.SLEEVE, J12.6, J12.GND1, J12.GND3, J14.1, J15.1, J15.3, J15.5, J15.7, J15.9, J15.11, J15.13, J15.15, J16.1, J17.1, J17.3, J17.5, J17.7, J17.9, J17.11, J17.13, J17.15, J18.1, R58.1, R63.2, R66.2, R100.1, S4.1, SJ8.1, SJ8.2, U3.12, U3.18, U3.63, U7.2, U8.3, U8.9, U8.16, U8.19, U9.7
GND2: C57.2, C58.2, C59.2, C60.2, C61.2, C63.2, C64.2, C65.2, C66.2, C67.2, C68.2, C69.1, C70.1, C71.2, C72.2, C73.2, C74.1, C75.2, C76.1, C78.2, C79.1, C80.1, C81.1, C82.1, C83.1, C84.1, J19.GND, J19.P$4, J20.SLEEVE, J21.6, J21.GND1, J21.GND3, J23.1, J24.1, J24.3, J24.5, J24.7, J24.9, J24.11, J24.13, J24.15, J25.1, J26.1, J26.3, J26.5, J26.7, J26.9, J26.11, J26.13, J26.15, J27.1, R108.1, R113.2, R116.2, R150.1, S6.1, SJ12.1, SJ12.2, U11.12, U11.18, U11.63, U12.2, U13.3, U13.9, U13.16, U13.19, U14.7
GND3: C85.2, C86.2, C87.2, C88.2, C89.2, C91.2, C92.2, C93.2, C94.2, C95.2, C96.2, C97.1, C98.1, C99.2, C100.2, C101.2, C102.1, C103.2, C104.1, C106.2, C107.1, C108.1, C109.1, C110.1, C111.1, C112.1, J28.GND, J28.P$4, J29.SLEEVE, J30.6, J30.GND1, J30.GND3, J32.1, J33.1, J33.3, J33.5, J33.7, J33.9, J33.11, J33.13, J33.15, J34.1, J35.1, J35.3, J35.5, J35.7, J35.9, J35.11, J35.13, J35.15, J36.1, R158.1, R163.2, R166.2, R200.1, S8.1, SJ16.1, SJ16.2, U16.12, U16.18, U16.63, U17.2, U18.3, U18.9, U18.16, U18.19, U19.7
I2S_BCLK: U4.34, U5.13
I2S_BCLK1: U3.34, U8.13
I2S_BCLK2: U11.34, U13.13
I2S_BCLK3: U16.34, U18.13
I2S_DOUT: U4.36, U5.14
I2S_DOUT1: U3.36, U8.14
I2S_DOUT2: U11.36, U13.14
I2S_DOUT3: U16.36, U18.14
I2S_LRCK: U4.33, U5.15
I2S_LRCK1: U3.33, U8.15
I2S_LRCK2: U11.33, U13.15
I2S_LRCK3: U16.33, U18.15
I2S_MCLK: U4.37, U5.12
I2S_MCLK1: U3.37, U8.12
I2S_MCLK2: U11.37, U13.12
I2S_MCLK3: U16.37, U18.12
LED1: LED1.C, U4.24
LED2: LED2.C, U3.24
LED3: LED3.C, U11.24
LED4: LED4.C, U16.24
LOUTL: C28.2, J2.TIP, R7.2, R9.1
LOUTL1: C53.2, J11.TIP, R57.2, R59.1
LOUTL2: C81.2, J20.TIP, R107.2, R109.1
LOUTL3: C109.2, J29.TIP, R157.2, R159.1
LOUTR: C29.2, J2.RING, R6.2
LOUTR1: C54.2, J11.RING, R56.2
LOUTR2: C82.2, J20.RING, R106.2
LOUTR3: C110.2, J29.RING, R156.2
MUTE: U4.8, U5.17
MUTE1: U3.8, U8.17
MUTE2: U11.8, U13.17
MUTE3: U16.8, U18.17
unnamed: J6.2, R11.1, R32.1
unnamed: C4.1, U2.4
unnamed: C9.2, U4.1
unnamed: C14.1, U4.31
unnamed: C16.2, U4.5, Y1.2
unnamed: C17.2, U4.6, Y1.1
unnamed: R16.1, S1.3
unnamed: C20.1, U4.47
unnamed: J4.4, R15.2
unnamed: R17.2, S1.1
unnamed: LED1.A, R19.2
unnamed: R20.1, U4.28
unnamed: R49.2, R50.2, U1.1
unnamed: C23.2, U5.18
unnamed: R6.1, U5.7
unnamed: C24.2, U5.2
unnamed: C24.1, U5.4
unnamed: C25.1, U5.5
unnamed: R7.1, U5.6
unnamed: C30.2, U6.2, U6.3
unnamed: C8.1, U7.4
unnamed: C34.2, U3.1
unnamed: J6.4, R12.1, R31.1
unnamed: J6.6, R13.1, R30.1
unnamed: J6.8, R18.1, R29.1
unnamed: J6.10, R21.1, R28.1
unnamed: J6.12, R22.1, R27.1
unnamed: J6.14, R23.1, R26.1
unnamed: R9.2, R10.1, U6.4
unnamed: J6.16, R24.1, R25.1
unnamed: C38.1, U3.31
unnamed: J4.3, SJ2.1
unnamed: C41.2, U3.5, Y2.2
unnamed: C42.2, U3.6, Y2.1
unnamed: J7.2, R40.1, R48.1
unnamed: J7.4, R39.1, R47.1
unnamed: J7.6, R38.1, R46.1
unnamed: J7.8, R37.1, R45.1
unnamed: J7.10, R36.1, R44.1
unnamed: J7.12, R35.1, R43.1
unnamed: J7.14, R34.1, R42.1
unnamed: J7.16, R33.1, R41.1
unnamed: C45.1, U3.47
unnamed: C48.2, U8.18
unnamed: C49.2, U8.2
unnamed: C49.1, U8.4
unnamed: C50.1, U8.5
unnamed: R56.1, U8.7
unnamed: R57.1, U8.6
unnamed: C55.2, U9.2, U9.3
unnamed: R59.2, R60.1, U9.4
unnamed: J14.4, R62.2
unnamed: R63.1, S3.3
unnamed: R64.2, S3.1
unnamed: LED2.A, R65.2
unnamed: R66.1, U3.28
unnamed: J14.3, SJ1.1
unnamed: J15.2, R67.1, R82.1
unnamed: J15.4, R68.1, R81.1
unnamed: J15.6, R69.1, R80.1
unnamed: J15.8, R70.1, R79.1
unnamed: J15.10, R71.1, R78.1
unnamed: J15.12, R72.1, R77.1
unnamed: J15.14, R73.1, R76.1
unnamed: J15.16, R74.1, R75.1
unnamed: J17.2, R83.1, R98.1
unnamed: J17.4, R84.1, R97.1
unnamed: J17.6, R85.1, R96.1
unnamed: J17.8, R86.1, R95.1
unnamed: J17.10, R87.1, R94.1
unnamed: J17.12, R88.1, R93.1
unnamed: J17.14, R89.1, R92.1
unnamed: J17.16, R90.1, R91.1
unnamed: R99.2, R100.2, U10.1
unnamed: C59.1, U12.4
unnamed: C62.2, U11.1
unnamed: C66.1, U11.31
unnamed: C69.2, U11.5, Y3.2
unnamed: C70.2, U11.6, Y3.1
unnamed: C73.1, U11.47
unnamed: C76.2, U13.18
unnamed: C77.2, U13.2
unnamed: C77.1, U13.4
unnamed: C78.1, U13.5
unnamed: R106.1, U13.7
unnamed: R107.1, U13.6
unnamed: C83.2, U14.2, U14.3
unnamed: R109.2, R110.1, U14.4
unnamed: J23.4, R112.2
unnamed: R113.1, S5.3
unnamed: R114.2, S5.1
unnamed: LED3.A, R115.2
unnamed: R116.1, U11.28
unnamed: J23.3, SJ9.1
unnamed: J24.2, R117.1, R132.1
unnamed: J24.4, R118.1, R131.1
unnamed: J24.6, R119.1, R130.1
unnamed: J24.8, R120.1, R129.1
unnamed: J24.10, R121.1, R128.1
unnamed: J24.12, R122.1, R127.1
unnamed: J24.14, R123.1, R126.1
unnamed: J24.16, R124.1, R125.1
unnamed: J26.2, R133.1, R148.1
unnamed: J26.4, R134.1, R147.1
unnamed: J26.6, R135.1, R146.1
unnamed: J26.8, R136.1, R145.1
unnamed: J26.10, R137.1, R144.1
unnamed: J26.12, R138.1, R143.1
unnamed: J26.14, R139.1, R142.1
unnamed: J26.16, R140.1, R141.1
unnamed: R149.2, R150.2, U15.1
unnamed: C87.1, U17.4
unnamed: C90.2, U16.1
unnamed: C94.1, U16.31
unnamed: C97.2, U16.5, Y4.2
unnamed: C98.2, U16.6, Y4.1
unnamed: C101.1, U16.47
unnamed: C104.2, U18.18
unnamed: C105.2, U18.2
unnamed: C105.1, U18.4
unnamed: C106.1, U18.5
unnamed: R156.1, U18.7
unnamed: R157.1, U18.6
unnamed: C111.2, U19.2, U19.3
unnamed: R159.2, R160.1, U19.4
unnamed: J32.4, R162.2
unnamed: R163.1, S7.3
unnamed: R164.2, S7.1
unnamed: LED4.A, R165.2
unnamed: R166.1, U16.28
unnamed: J32.3, SJ13.1
unnamed: J33.2, R167.1, R182.1
unnamed: J33.4, R168.1, R181.1
unnamed: J33.6, R169.1, R180.1
unnamed: J33.8, R170.1, R179.1
unnamed: J33.10, R171.1, R178.1
unnamed: J33.12, R172.1, R177.1
unnamed: J33.14, R173.1, R176.1
unnamed: J33.16, R174.1, R175.1
unnamed: J35.2, R183.1, R198.1
unnamed: J35.4, R184.1, R197.1
unnamed: J35.6, R185.1, R196.1
unnamed: J35.8, R186.1, R195.1
unnamed: J35.10, R187.1, R194.1
unnamed: J35.12, R188.1, R193.1
unnamed: J35.14, R189.1, R192.1
unnamed: J35.16, R190.1, R191.1
unnamed: R199.2, R200.2, U20.1
PLAYOUT: J8.2, U4.25
PLAYOUT1: J16.2, U3.25
PLAYOUT2: J25.2, U11.25
PLAYOUT3: J34.2, U16.25
RXD: R14.1, R15.1, U4.43
RXD1: R61.1, R62.1, U3.43
RXD2: R111.1, R112.1, U11.43
RXD3: R161.1, R162.1, U16.43
SD_CD: J3.CD1, J3.CD2, U4.26
SD_CD1: J12.CD1, J12.CD2, U3.26
SD_CD2: J21.CD1, J21.CD2, U11.26
SD_CD3: J30.CD1, J30.CD2, U16.26
SD_CK: J3.5, U4.53
SD_CK1: J12.5, U3.53
SD_CK2: J21.5, U11.53
SD_CK3: J30.5, U16.53
SD_CMD: J3.3, R3.1, U4.54
SD_CMD1: J12.3, R53.1, U3.54
SD_CMD2: J21.3, R103.1, U11.54
SD_CMD3: J30.3, R153.1, U16.54
SD_D0: J3.7, R2.1, U4.39
SD_D1: J3.8, R1.1, U4.40
SD_D2: J3.1, R5.1, U4.51
SD_D3: J3.2, R4.1, U4.52
SD_D4: J12.8, R51.1, U3.40
SD_D5: J12.7, R52.1, U3.39
SD_D6: J12.2, R54.1, U3.52
SD_D7: J12.1, R55.1, U3.51
SD_D8: J21.8, R101.1, U11.40
SD_D9: J21.7, R102.1, U11.39
SD_D10: J21.2, R104.1, U11.52
SD_D11: J21.1, R105.1, U11.51
SD_D12: J30.8, R151.1, U16.40
SD_D13: J30.7, R152.1, U16.39
SD_D14: J30.2, R154.1, U16.52
SD_D15: J30.1, R155.1, U16.51
SPKR+: J5.2, U6.8
SPKR+1: J13.2, U9.8
SPKR+2: J22.2, U14.8
SPKR+3: J31.2, U19.8
SPKR-: J5.1, R10.2, U6.5
SPKR-1: J13.1, R60.2, U9.5
SPKR-2: J22.1, R110.2, U14.5
SPKR-3: J31.1, R160.2, U19.5
TRIG00: R40.2, U4.14
TRIG01: R39.2, U4.15
TRIG02: R38.2, U4.16
TRIG03: R37.2, U4.17
TRIG04: R36.2, U4.20
TRIG05: R35.2, U4.21
TRIG06: R34.2, U4.22
TRIG07: R33.2, U4.23
TRIG08: R11.2, U4.61
TRIG09: R12.2, U4.62
TRIG10: R13.2, U4.29
TRIG11: R18.2, U4.44
TRIG12: R21.2, U4.45
TRIG13: R22.2, U4.46
TRIG14: R23.2, U4.49
TRIG15: R24.2, U4.50
TRIG16: R67.2, U3.14
TRIG17: R68.2, U3.15
TRIG18: R69.2, U3.16
TRIG19: R70.2, U3.17
TRIG20: R71.2, U3.20
TRIG21: R72.2, U3.21
TRIG22: R73.2, U3.22
TRIG23: R74.2, U3.23
TRIG24: R83.2, U3.61
TRIG25: R84.2, U3.62
TRIG26: R85.2, U3.29
TRIG27: R86.2, U3.44
TRIG28: R87.2, U3.45
TRIG29: R88.2, U3.46
TRIG30: R89.2, U3.49
TRIG31: R90.2, U3.50
TRIG32: R117.2, U11.14
TRIG33: R118.2, U11.15
TRIG34: R119.2, U11.16
TRIG35: R120.2, U11.17
TRIG36: R121.2, U11.20
TRIG37: R122.2, U11.21
TRIG38: R123.2, U11.22
TRIG39: R124.2, U11.23
TRIG40: R133.2, U11.61
TRIG41: R134.2, U11.62
TRIG42: R135.2, U11.29
TRIG43: R136.2, U11.44
TRIG44: R137.2, U11.45
TRIG45: R138.2, U11.46
TRIG46: R139.2, U11.49
TRIG47: R140.2, U11.50
TRIG48: R167.2, U16.14
TRIG49: R168.2, U16.15
TRIG50: R169.2, U16.16
TRIG51: R170.2, U16.17
TRIG52: R171.2, U16.20
TRIG53: R172.2, U16.21
TRIG54: R173.2, U16.22
TRIG55: R174.2, U16.23
TRIG56: R183.2, U16.61
TRIG57: R184.2, U16.62
TRIG58: R185.2, U16.29
TRIG59: R186.2, U16.44
TRIG60: R187.2, U16.45
TRIG61: R188.2, U16.46
TRIG62: R189.2, U16.49
TRIG63: R190.2, U16.50
TXD: J4.5, U4.42
TXD1: J14.5, U3.42
TXD2: J23.5, U11.42
TXD3: J32.5, U16.42
VCC: C5.1, C9.1, C10.1, C11.1, C12.1, C13.1, C15.1, C18.1, C19.1, C21.2, C22.1, C26.2, C27.2, J3.4, J8.3, R1.2, R2.2, R3.2, R4.2, R5.2, R14.2, R17.1, R19.1, R25.2, R26.2, R27.2, R28.2, R29.2, R30.2, R31.2, R32.2, R41.2, R42.2, R43.2, R44.2, R45.2, R46.2, R47.2, R48.2, SJ4.1, SJ4.2, U2.5, U4.13, U4.19, U4.32, U4.48, U4.64, U5.1, U5.8, U5.20
VCC1: C32.1, C34.1, C35.1, C36.1, C37.1, C39.1, C40.1, C43.1, C44.1, C46.2, C47.1, C51.2, C52.2, J12.4, J16.3, R51.2, R52.2, R53.2, R54.2, R55.2, R61.2, R64.1, R65.1, R75.2, R76.2, R77.2, R78.2, R79.2, R80.2, R81.2, R82.2, R91.2, R92.2, R93.2, R94.2, R95.2, R96.2, R97.2, R98.2, SJ7.1, SJ7.2, U3.13, U3.19, U3.32, U3.48, U3.64, U7.5, U8.1, U8.8, U8.20
VCC2: C60.1, C62.1, C63.1, C64.1, C65.1, C67.1, C68.1, C71.1, C72.1, C74.2, C75.1, C79.2, C80.2, J21.4, J25.3, R101.2, R102.2, R103.2, R104.2, R105.2, R111.2, R114.1, R115.1, R125.2, R126.2, R127.2, R128.2, R129.2, R130.2, R131.2, R132.2, R141.2, R142.2, R143.2, R144.2, R145.2, R146.2, R147.2, R148.2, SJ11.1, SJ11.2, U11.13, U11.19, U11.32, U11.48, U11.64, U12.5, U13.1, U13.8, U13.20
VCC3: C88.1, C90.1, C91.1, C92.1, C93.1, C95.1, C96.1, C99.1, C100.1, C102.2, C103.1, C107.2, C108.2, J30.4, J34.3, R151.2, R152.2, R153.2, R154.2, R155.2, R161.2, R164.1, R165.1, R175.2, R176.2, R177.2, R178.2, R179.2, R180.2, R181.2, R182.2, R191.2, R192.2, R193.2, R194.2, R195.2, R196.2, R197.2, R198.2, SJ15.1, SJ15.2, U16.13, U16.19, U16.32, U16.48, U16.64, U17.5, U18.1, U18.8, U18.20
VIN: C1.1, J1.VIN0, J9.2, U1.3
VIN1: C33.1, J10.VIN0, J18.2, U10.3
VIN2: C61.1, J19.VIN0, J27.2, U15.3
VIN3: C89.1, J28.VIN0, J36.2, U20.3

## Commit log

2013-04-04 added Jamie's project files
    [mp3triggerv3.brd, mp3triggerv3.sch]
2013-04-09 v010
    files sent to Jamie
    [mp3triggerv3.brd, mp3triggerv3.sch]
2013-07-18 v31, ready for review
    [mp3triggerv3.brd, mp3triggerv3.sch]
2013-07-23 v31, ready for protos, now dubbed 'pro' version
    [mp3triggerv3.brd, mp3triggerv3.sch]
2013-07-25 changed version mark back to v30
    [mp3triggerv3.brd]
2013-09-20 v04 hardware files
    [wavtrigger.brd, wavtrigger.sch]
2013-10-02 Next round of protos ready for order, v04
    [wavtrigger.brd, wavtrigger.sch]
2013-11-01 v10 red ready
    [wavtrigger.brd, wavtrigger.sch]
2013-11-04 v10, frame update
    [wavtrigger.brd, wavtrigger.sch]
2013-11-05 Added local micro fiducials
    [wavtrigger.brd, wavtrigger.sch]
2013-11-05 Created Panel
    [wavtrigger-panel-v10.brd]
2014-01-16 updated v10, changed C24-25 values to improve audio quality
    [wavtrigger.brd, wavtrigger.sch]
2014-06-30 changed micro fid to regular
    also deleted "wrong" panel, re-doing it
    [wavtrigger-panel-v10.brd, wavtrigger.brd, wavtrigger.sch]
2014-06-30 re-created panel v10
    [wavtrigger-Panel-v10.brd]
2014-06-30 Reverting back to panel v10
    [wavtrigger-Panel-v10.brd]

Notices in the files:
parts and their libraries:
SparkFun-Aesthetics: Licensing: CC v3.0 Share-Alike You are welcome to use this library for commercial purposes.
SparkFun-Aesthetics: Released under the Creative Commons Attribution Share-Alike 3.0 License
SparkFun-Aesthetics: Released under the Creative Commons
